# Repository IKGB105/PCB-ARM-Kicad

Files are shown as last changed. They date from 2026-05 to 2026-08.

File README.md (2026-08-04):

# ARM Processor PCB Design (KiCad)

PCB design for an ARM-based board ("ArmVaquita"), from schematic capture through component placement and trace routing, built in KiCad.

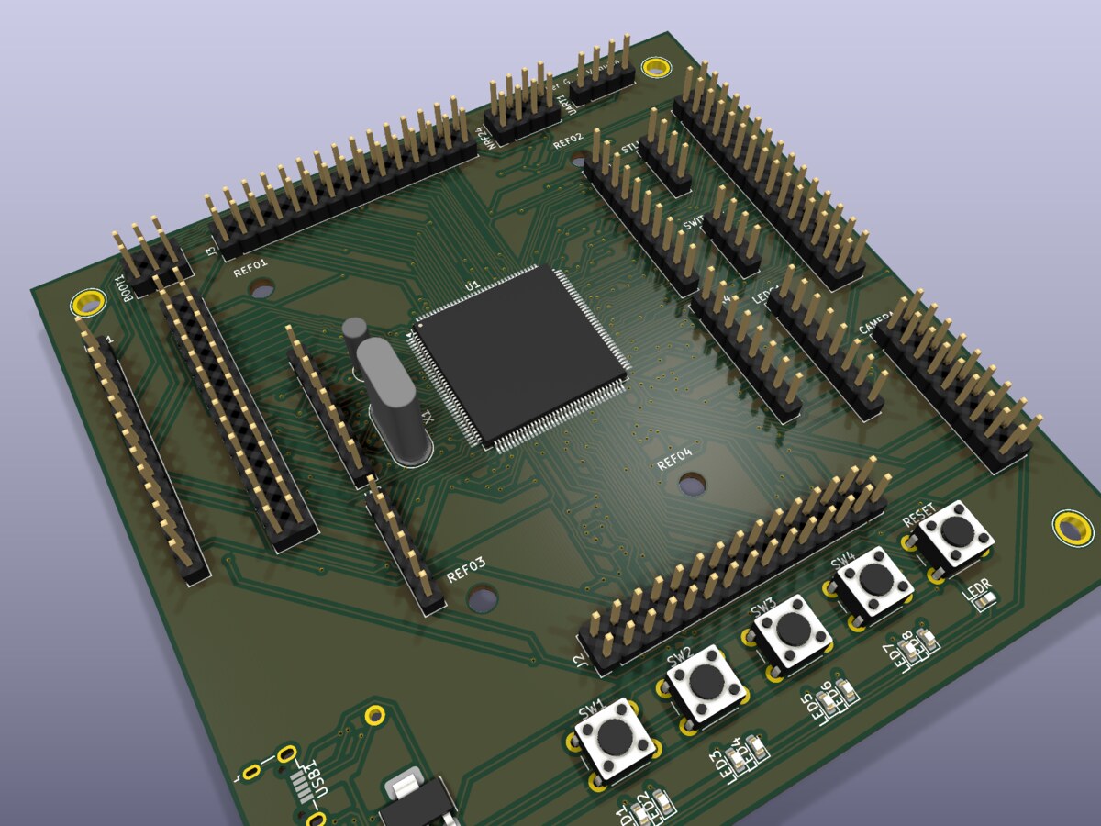
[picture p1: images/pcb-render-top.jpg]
3D render of the routed board


## What's in this repo

- `ArmVaquita.kicad_pro` / `.kicad_pcb` — earlier board revision
- `Placa routeada/` — final routed version (`PLACAROUTEADA.kicad_pcb`), fully routed with copper pours and vias
- `Plot/` — exported Gerber/drill files, ready for fabrication

## Board features

- ARM Cortex-M MCU in QFP package as the central component
- USB connector for power/programming
- 4 user pushbuttons + reset button
- 8 status LEDs
- Multiple expansion headers (BOOT, camera interface, general I/O)
- Full 2-layer routing with ground pour

The 3D render above was generated directly from the routed board file with `kicad-cli pcb render`.

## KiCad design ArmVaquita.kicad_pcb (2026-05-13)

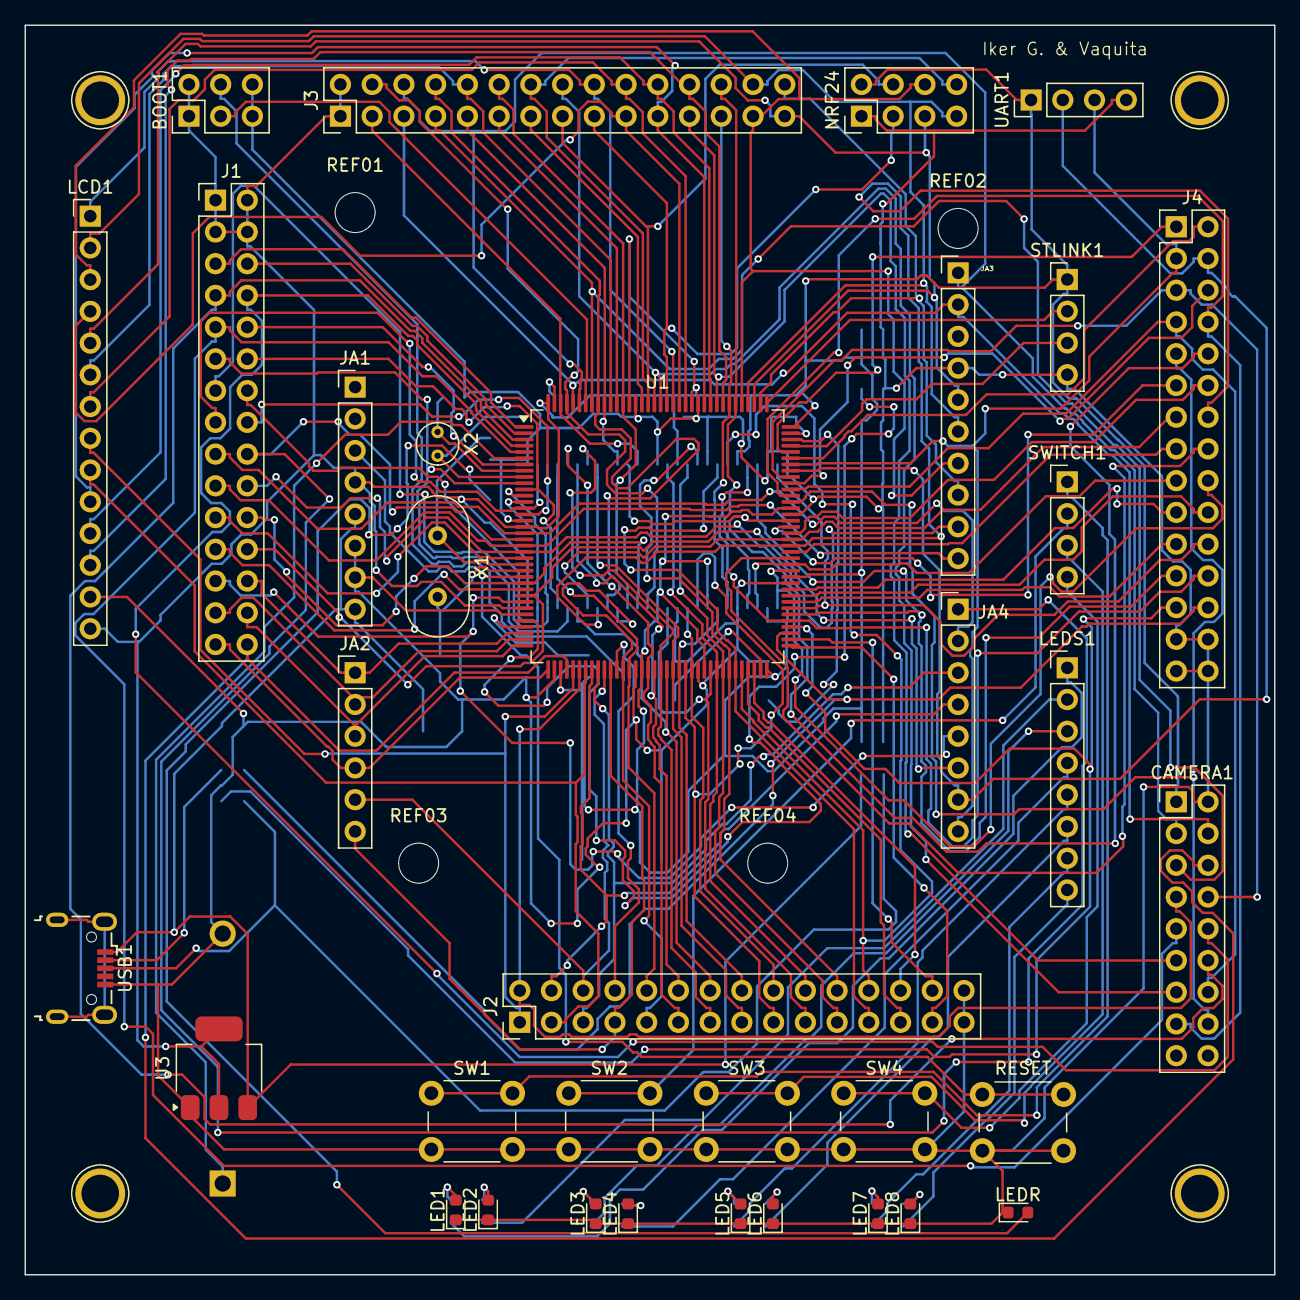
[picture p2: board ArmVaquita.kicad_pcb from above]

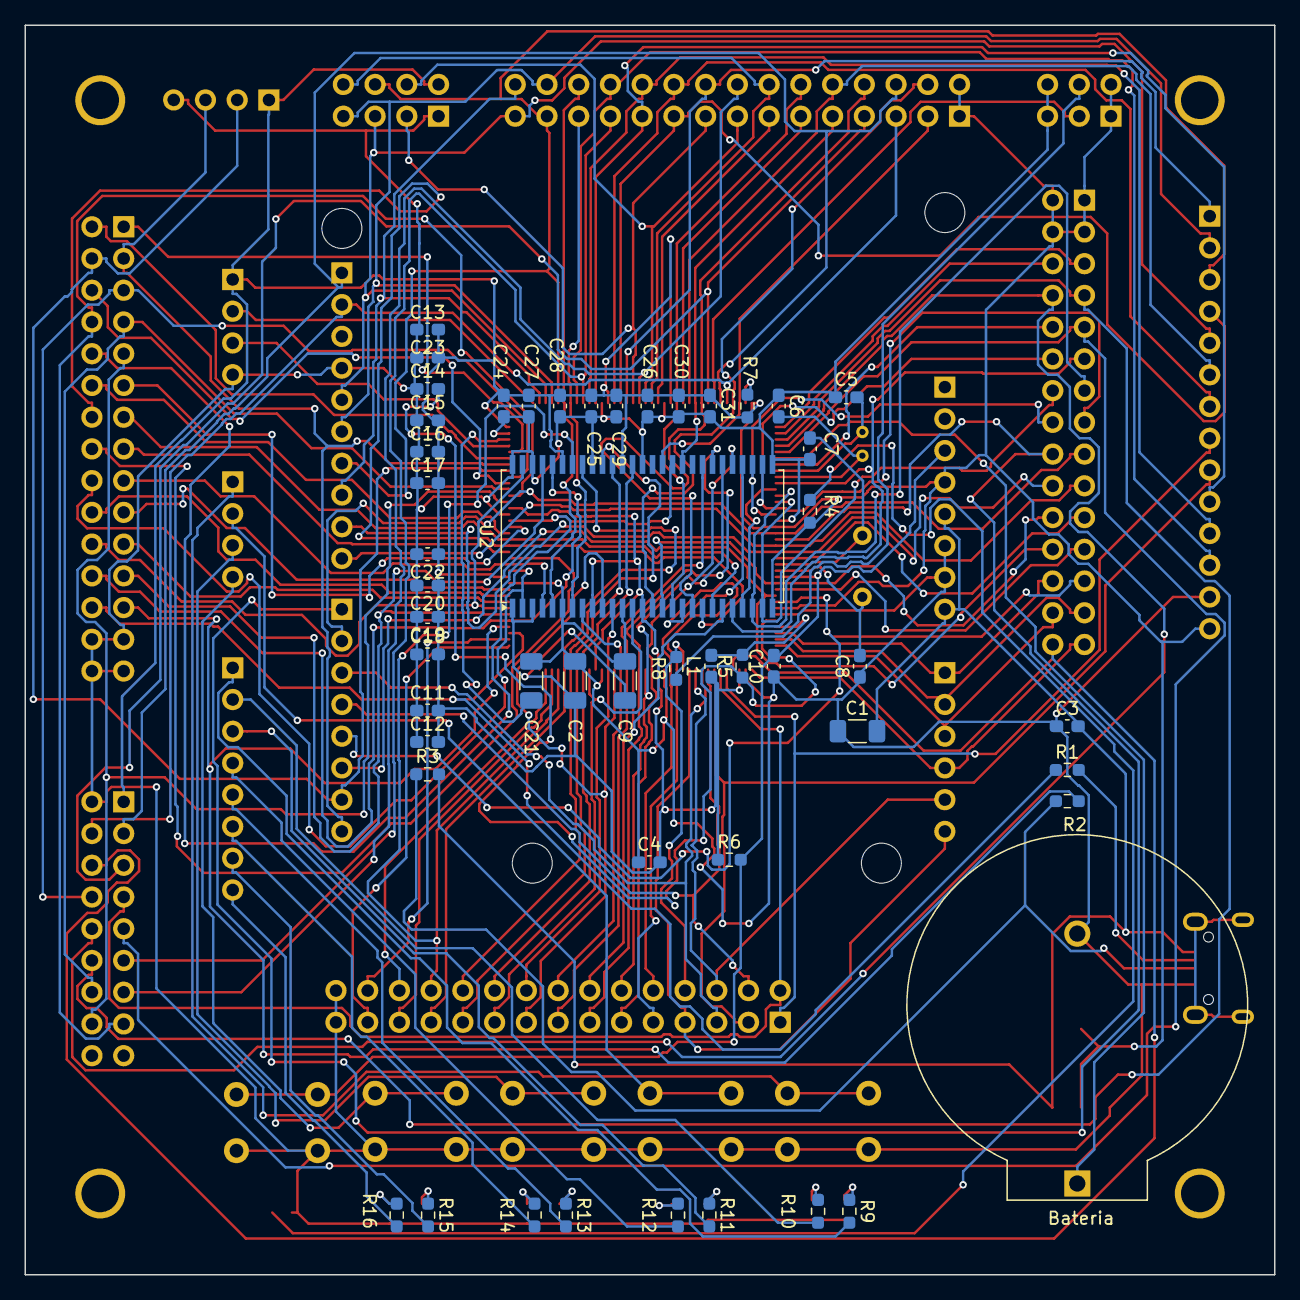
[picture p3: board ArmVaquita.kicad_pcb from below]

Board: 2 copper layers, 100.0 x 100.0 mm, 93 parts (51 on the bottom side), 149 nets.

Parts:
BOOT1: Conn2x3; PinHeader_2x03_P2.54mm_Vertical
Bateria: Portapila; BatteryHolder_ComfortableElectronic_CH273-2450_1x2450
C1, C2: 10uF; C_1206_3216Metric_Pad1.33x1.80mm_HandSolder
C3, C4, C10, C11, C12, C13, C14, C15, C16, C17, C18, C19, C20, C22, C23, C24, C25, C26, C27, C28, C29, C30, C31: 100nF; C_0603_1608Metric_Pad1.08x0.95mm_HandSolder
C5, C6: 12pF; C_0603_1608Metric_Pad1.08x0.95mm_HandSolder
C7, C8: 8pF; C_0603_1608Metric_Pad1.08x0.95mm_HandSolder
C9, C21: 2.2uF; C_1206_3216Metric_Pad1.33x1.80mm_HandSolder
CAMERA1: Conn2x9; PinHeader_2x09_P2.54mm_Vertical
Hoyo1: T#1; TestPoint_Plated_Hole_D3.0mm
Hoyo2: T#4; TestPoint_Plated_Hole_D3.0mm
Hoyo3: T#3; TestPoint_Plated_Hole_D3.0mm
Hoyo4: T#2; TestPoint_Plated_Hole_D3.0mm
J1, J3, J4: Conn2x15; PinHeader_2x15_P2.54mm_Vertical
J2: Con2x15; PinHeader_2x15_P2.54mm_Vertical
JA1, JA4: HDR1X8; PinHeader_1x08_P2.54mm_Vertical
JA2: HDR1X6; PinHeader_1x06_P2.54mm_Vertical
JA3: HDR1X10; PinHeader_1x10_P2.54mm_Vertical
L1: 10uH; L_0603_1608Metric_Pad1.05x0.95mm_HandSolder
LCD1: Conn1x14; PinHeader_1x14_P2.54mm_Vertical
LED1, LED2, LED3, LED4, LED5, LED6, LED7, LED8: AZUL; LED_0603_1608Metric
LEDR: ROJO; LED_0603_1608Metric
LEDS1: Conn1x8; PinHeader_1x08_P2.54mm_Vertical
NRF24: Conn2x4; PinHeader_2x04_P2.54mm_Vertical
R1, R2: 22; R_0603_1608Metric_Pad0.98x0.95mm_HandSolder
R3, R6, R8: 10k; R_0603_1608Metric_Pad0.98x0.95mm_HandSolder
R4, R9, R10, R11, R12, R13, R14, R15, R16: 220; R_0603_1608Metric_Pad0.98x0.95mm_HandSolder
R5, R7: 0; R_0603_1608Metric_Pad0.98x0.95mm_HandSolder
REF01, REF02, REF03, REF04: MountingHole; MountingHole_3.2mm_M3_DIN965
RESET: SW_Push; SW_PUSH_6mm_H4.3mm
STLINK1: Conn_01x04; PinHeader_1x04_P2.54mm_Vertical
SW1, SW2, SW3, SW4: SW_Push; SW_PUSH_6mm_H4.3mm
SWITCH1: Conn1x4; PinHeader_1x04_P2.54mm_Vertical
U1: STM32F446ZETx; LQFP-144_20x20mm_P0.5mm
U2: IS42S16400J-xT; TSOP-II-54_22.2x10.16mm_P0.8mm
U3: LM317_SOT-223; SOT-223-3_TabPin2
UART1: Conn1x4; PinHeader_1x04_P2.54mm_Vertical
USB1: USB_B_Mini; USB_Micro-B_Wuerth_629105150521
X1: 8MHz; Crystal_HC18-U_Vertical
X2: 32.768KHz; Crystal_C38-LF_D3.0mm_L8.0mm_Vertical

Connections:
+5V: C1.2, C3.2, JA1.5, JA1.8, R3.2, U3.3 (VI), USB1.1 (VBUS)
/8: C5.2, U1.8 (PC14), X2.1
/9: C6.2, U1.9 (PC15), X2.2
/23: C7.2, U1.23 (PH0), X1.1
/24: C8.2, U1.24 (PH1), X1.2
/32: C14.2, R5.1, U1.32 (VREF+)
/33: L1.2, R5.2, U1.33 (VDDA)
/71: C9.2, U1.71 (VCAP_1)
/106: C21.1, U1.106 (VCAP_2)
/BOOT0: BOOT1.3, U1.138 (BOOT0)
/BOOT1(PB2): J2.8, R8.2, U1.48 (PB2)
/PA0: J1.26, JA2.1, U1.34 (PA0)
/PA1: J1.27, JA2.2, U1.35 (PA1)
/PA2: J1.28, JA2.3, U1.36 (PA2)
/PA3: J1.29, JA2.4, U1.37 (PA3)
/PA4: CAMERA1.6, J1.30, U1.40 (PA4)
/PA5: J2.1, LCD1.8, U1.41 (PA5)
/PA6: CAMERA1.7, J2.2, U1.42 (PA6)
/PA7: J2.3, LCD1.9, U1.43 (PA7)
/PA8: CAMERA1.8, J4.5, U1.100 (PA8)
/PA9: J4.4, JA4.7, U1.101 (PA9), UART1.2
/PA10: J4.3, JA4.8, U1.102 (PA10), UART1.3
/PA11: J4.2, U1.103 (PA11)
/PA12: J4.1, U1.104 (PA12)
/PA15: J3.30, JA3.8, U1.110 (PA15)
/PB0: J2.6, JA2.5, U1.46 (PB0)
/PB1: J2.7, JA2.6, U1.47 (PB1)
/PB3: J3.11, U1.133 (PB3)
/PB4: J3.10, LCD1.6, U1.134 (PB4)
/PB5: J3.9, U1.135 (PB5), U2.37 (CKE)
/PB6: J3.8, U1.136 (PB6), U2.19 (~CS)
/PB7: CAMERA1.5, J3.7, U1.137 (PB7)
/PB8: CAMERA1.3, J3.6, JA3.1, U1.139 (PB8)
/PB9: CAMERA1.4, J3.5, JA3.2, U1.140 (PB9)
/PB10: J2.25, U1.69 (PB10)
/PB11: J2.26, U1.70 (PB11)
/PB12: J2.27, U1.73 (PB12)
/PB13: J2.28, U1.74 (PB13)
/PB14: J4.26, R1.1, U1.75 (PB14)
/PB15: J4.25, R2.2, U1.76 (PB15)
/PC0: J1.22, U1.26 (PC0), U2.16 (~WE)
/PC1: J1.23, U1.27 (PC1)
/PC2: J1.24, JA4.6, U1.28 (PC2)
/PC3: J1.25, JA4.5, U1.29 (PC3)
/PC4: J2.4, JA4.4, U1.44 (PC4)
/PC5: J2.5, JA4.3, U1.45 (PC5)
/PC6: CAMERA1.16, J4.9, U1.96 (PC6)
/PC7: CAMERA1.15, J4.8, U1.97 (PC7)
/PC8: CAMERA1.14, J4.7, U1.98 (PC8)
/PC9: J4.6, U1.99 (PC9)
/PC10: J3.29, JA3.5, LCD1.5, NRF24.5, U1.111 (PC10)
/PC11: J3.28, JA3.6, LCD1.2, NRF24.7, U1.112 (PC11)
/PC12: J3.27, JA3.7, LCD1.3, NRF24.6, U1.113 (PC12)
/PC13: J1.10, U1.7 (PC13)
/PD0: J3.26, U1.114 (PD0), U2.5 (DQ2)
/PD1: J3.25, U1.115 (PD1), U2.7 (DQ3)
/PD2: J3.24, LCD1.12, U1.116 (PD2)
/PD3: CAMERA1.11, J3.23, U1.117 (PD3)
/PD4: J3.22, LCD1.11, U1.118 (PD4)
/PD5: J3.21, LCD1.10, U1.119 (PD5)
/PD6: J3.20, LCD1.7, U1.122 (PD6)
/PD7: J3.19, LCD1.4, U1.123 (PD7)
/PD8: J4.24, U1.77 (PD8), U2.50 (DQ13)
/PD9: J4.23, U1.78 (PD9), U2.51 (DQ14)
/PD10: J4.22, U1.79 (PD10), U2.53 (DQ15)
/PD11: J4.21, U1.80 (PD11)
/PD12: J4.20, U1.81 (PD12)
/PD13: J4.19, U1.82 (PD13)
/PD14: J4.18, U1.85 (PD14), U2.2 (DQ0)
/PD15: J4.17, U1.86 (PD15), U2.4 (DQ1)
/PE0: J3.4, U1.141 (PE0), U2.15 (LDQM)
/PE1: J3.3, U1.142 (PE1), U2.39 (UDQM)
/PE2: J1.5, U1.1 (PE2)
/PE3: J1.6, U1.2 (PE3)
/PE4: CAMERA1.12, J1.7, U1.3 (PE4)
/PE5: CAMERA1.10, J1.8, U1.4 (PE5)
/PE6: CAMERA1.9, J1.9, U1.5 (PE6)
/PE7: J2.16, U1.58 (PE7), U2.8 (DQ4)
/PE8: J2.17, U1.59 (PE8), U2.10 (DQ5)
/PE9: J2.18, U1.60 (PE9), U2.11 (DQ6)
/PE10: J2.19, U1.63 (PE10), U2.13 (DQ7)
/PE11: J2.20, U1.64 (PE11), U2.42 (DQ8)
/PE12: J2.21, U1.65 (PE12), U2.44 (DQ9)
/PE13: J2.22, U1.66 (PE13), U2.45 (DQ10)
/PE14: J2.23, U1.67 (PE14), U2.47 (DQ11)
/PE15: J2.24, U1.68 (PE15), U2.48 (DQ12)
/PF0: J1.11, U1.10 (PF0), U2.23 (A0)
/PF1: J1.12, U1.11 (PF1), U2.24 (A1)
/PF2: J1.13, U1.12 (PF2), U2.25 (A2)
/PF3: J1.14, U1.13 (PF3), U2.26 (A3)
/PF4: J1.15, U1.14 (PF4), U2.29 (A4)
/PF5: J1.16, U1.15 (PF5), U2.30 (A5)
/PF6: J1.17, JA4.2, U1.18 (PF6)
/PF7: J1.18, JA4.1, U1.19 (PF7)
/PF8: J1.19, JA3.10, U1.20 (PF8)
/PF9: J1.20, JA3.9, U1.21 (PF9)
/PF10: J1.21, U1.22 (PF10)
/PF11: J2.9, U1.49 (PF11), U2.18 (~RAS)
/PF12: J2.10, U1.50 (PF12), U2.31 (A6)
/PF13: J2.11, U1.53 (PF13), U2.32 (A7)
/PF14: J2.12, U1.54 (PF14), U2.33 (A8)
/PF15: J2.13, U1.55 (PF15), U2.34 (A9)
/PG0: J2.14, U1.56 (PG0), U2.22 (A10)
/PG1: J2.15, U1.57 (PG1), U2.35 (A11)
/PG2: J4.16, U1.87 (PG2)
/PG3: J4.15, U1.88 (PG3)
/PG4: J4.14, U1.89 (PG4), U2.20 (BA0)
/PG5: J4.13, U1.90 (PG5), U2.21 (BA1)
/PG6: J4.12, U1.91 (PG6)
/PG7: J4.11, U1.92 (PG7)
/PG8: J4.10, U1.93 (PG8), U2.38 (CLK)
/PG9: J3.18, LCD1.1, U1.124 (PG9)
/PG10: J3.17, NRF24.3, U1.125 (PG10)
/PG11: CAMERA1.13, J3.16, U1.126 (PG11)
/PG12: J3.15, NRF24.4, U1.127 (PG12)
/PG13: J3.14, NRF24.8, U1.128 (PG13)
/PG14: J3.13, U1.129 (PG14)
/PG15: J3.12, U1.132 (PG15), U2.17 (~CAS)
/RES: C10.2, JA1.3, R6.2, RESET.2, U1.25 (NRST)
/SWCLK: STLINK1.2, U1.109 (PA14)
/SWDIO: STLINK1.3, U1.105 (PA13)
/VBAT: Bateria.1, U1.6 (VBAT)
Earth: BOOT1.5, BOOT1.6, Bateria.2, C1.1, C2.1, C3.1, C4.1, C5.1, C6.1, C7.1, C8.1, C9.1, C10.1, C11.1, C12.1, C13.1, C14.1, C15.1, C16.1, C17.1, C18.1, C19.2, C20.2, C21.2, C22.2, C23.2, C24.2, C25.2, C26.1, C27.1, C28.1, C29.2, C30.2, C31.2, CAMERA1.2, J2.29, J2.30, J4.27, J4.28, J4.29, J4.30, JA1.6, JA1.7, JA3.4, LCD1.13, LED1.1 (K), LED2.1 (K), LED3.1 (K), LED4.1 (K), LED5.1 (K), LED6.1 (K), LED7.1 (K), LED8.1 (K), LEDR.1 (K), NRF24.1, RESET.1, STLINK1.4, SW1.2, SW2.2, SW3.2, SW4.2, U1.16 (VSS), U1.31 (VSSA), U1.38 (VSS), U1.51 (VSS), U1.61 (VSS), U1.83 (VSS), U1.94 (VSS), U1.107 (VSS), U1.120 (VSS), U1.130 (VSS), U2.6 (GNDQ), U2.12 (GNDQ), U2.28 (GND), U2.41 (GND), U2.46 (GNDQ), U2.52 (GNDQ), U2.54 (GND), U3.1 (ADJ), UART1.4, USB1.5 (GND)
unnamed: BOOT1.4, R8.1
unnamed: LED1.2 (A), R9.1
unnamed: LED2.2 (A), R10.1
unnamed: LED3.2 (A), R11.1
unnamed: LED4.2 (A), R12.1
unnamed: LED5.2 (A), R13.1
unnamed: LED6.2 (A), R14.1
unnamed: LED7.2 (A), R15.1
unnamed: LED8.2 (A), R16.1
unnamed: LEDR.2 (A), R4.2
unnamed: LEDS1.1, R9.2
unnamed: LEDS1.2, R10.2
unnamed: LEDS1.3, R11.2
unnamed: LEDS1.4, R12.2
unnamed: LEDS1.5, R13.2
unnamed: LEDS1.6, R14.2
unnamed: LEDS1.7, R15.2
unnamed: LEDS1.8, R16.2
unnamed: SW1.1, SWITCH1.1
unnamed: SW2.1, SWITCH1.2
unnamed: SW3.1, SWITCH1.3
unnamed: SW4.1, SWITCH1.4
unnamed: R7.2, U1.143 (PDR_ON)
unnamed: R2.1, R3.1, USB1.3 (D+)
unnamed: R1.2, USB1.2 (D-)
VDD: BOOT1.1, BOOT1.2, C2.2, C4.2, C11.2, C12.2, C13.2, C15.2, C16.2, C17.2, C18.2, C19.1, C20.1, C22.1, C23.1, C24.1, C25.1, C26.2, C27.2, C28.2, C29.1, C30.1, C31.1, CAMERA1.1, J1.1, J1.2, J1.3, J1.4, J3.1, J3.2, JA1.4, L1.1, LCD1.14, NRF24.2, R4.1, R6.1, R7.1, STLINK1.1, U1.17 (VDD), U1.30 (VDD), U1.39 (VDD), U1.52 (VDD), U1.62 (VDD), U1.72 (VDD), U1.84 (VDD), U1.95 (VDDUSB), U1.108 (VDD), U1.121 (VDD), U1.131 (VDD), U1.144 (VDD), U2.1 (VDD), U2.3 (VDDQ), U2.9 (VDDQ), U2.14 (VDD), U2.27 (VDD), U2.43 (VDDQ), U2.49 (VDDQ), U3.2 (VO), UART1.1
